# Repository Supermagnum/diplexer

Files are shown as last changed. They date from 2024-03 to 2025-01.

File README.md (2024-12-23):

# diplexer
HF+6M lowpass and 4M highpass

The lowpass filter has: 71.5mhz -42dB. 
Highpass filter 52.5mhz -45dB. 50.5mhz -50db

Highpass Ltspice analysis setup:
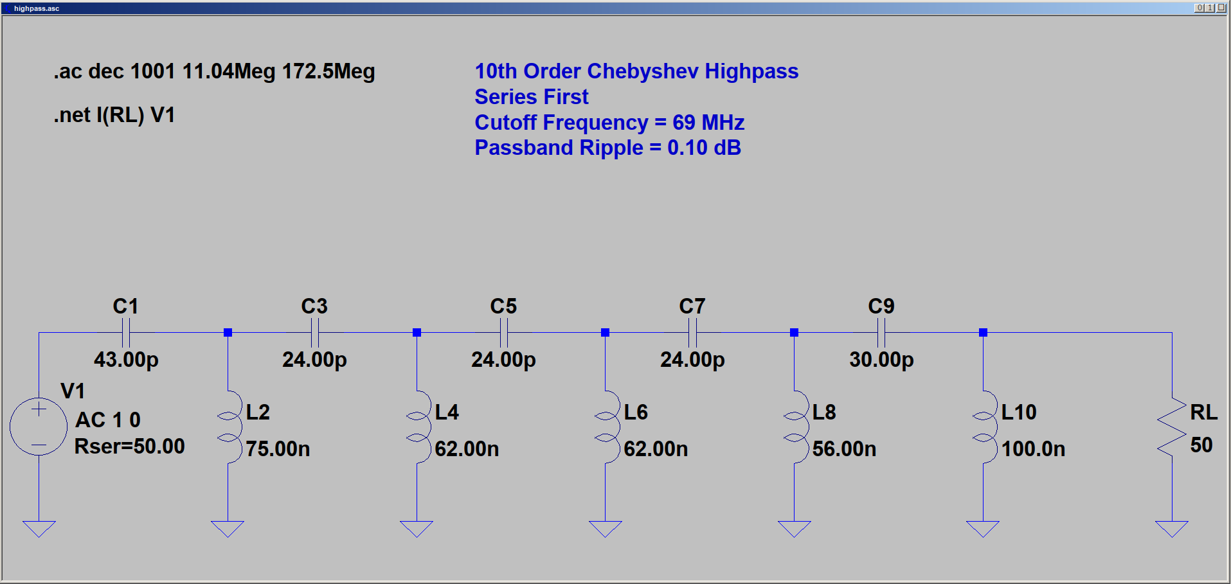
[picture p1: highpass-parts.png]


Highpass frequency analysis ( insertion loss, insertion phase, and return loss):
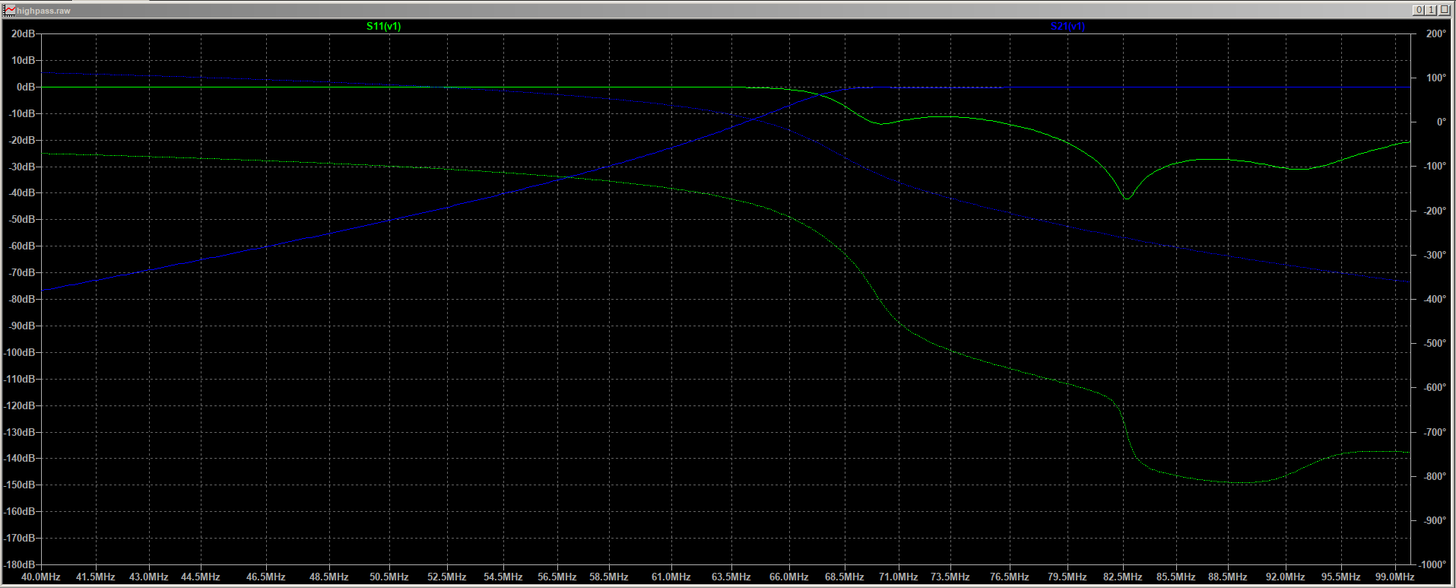
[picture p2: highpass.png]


Highpass Z-in and Z out analysis:
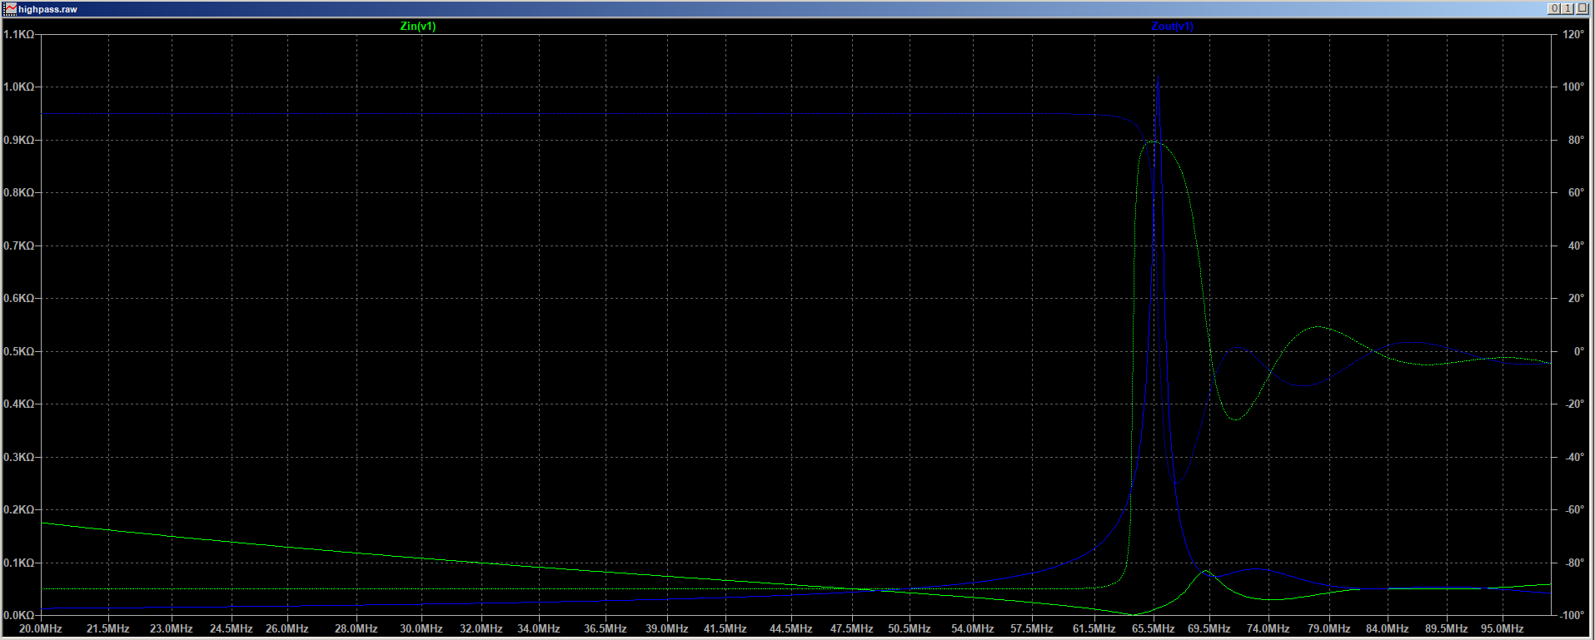
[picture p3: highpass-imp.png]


Lowpass LTspice analysis setup:
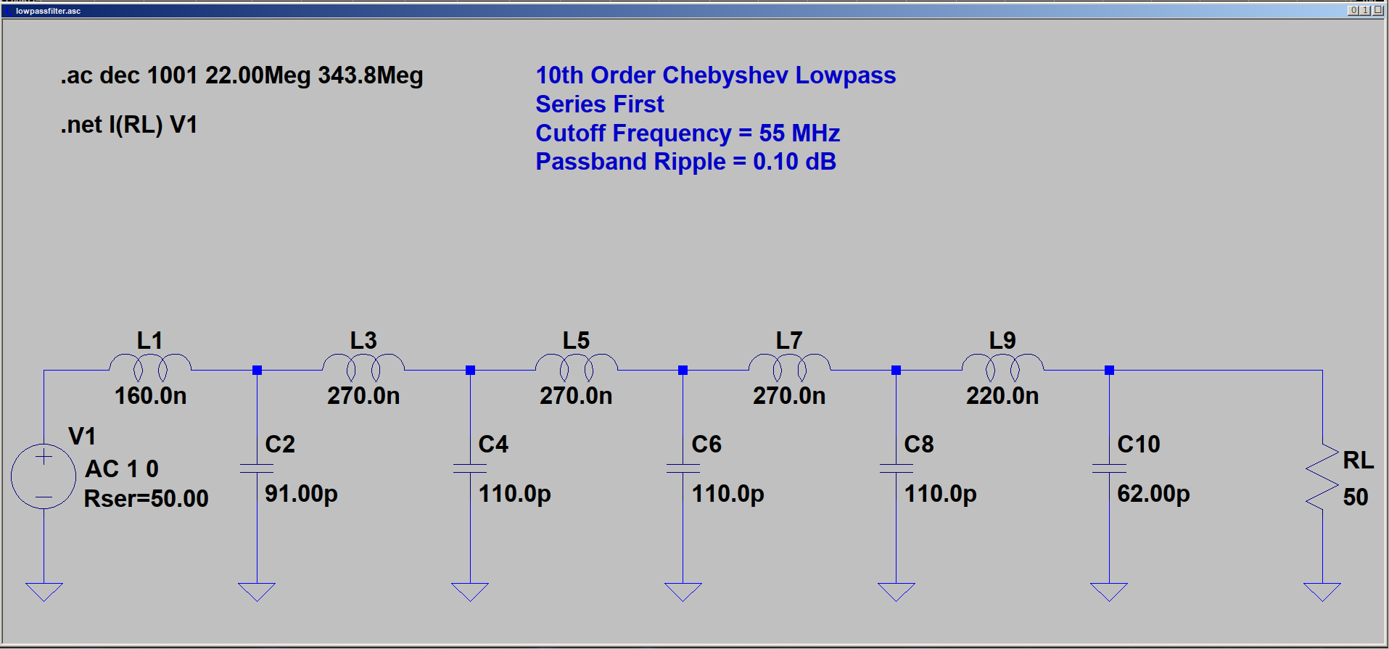
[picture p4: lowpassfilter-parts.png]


Lowpass filter frequency analysis ( insertion loss, insertion phase, and return loss):
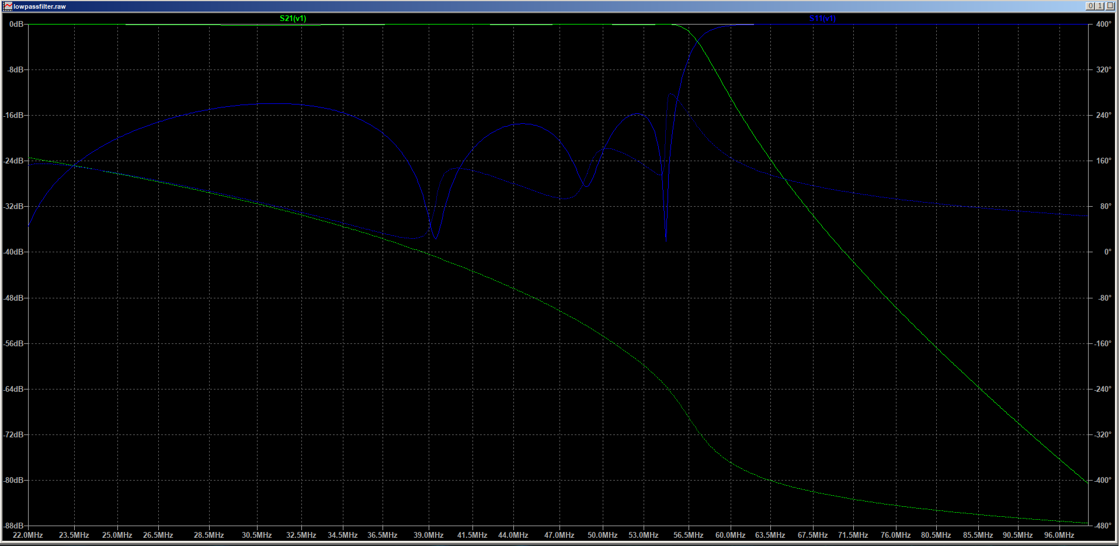
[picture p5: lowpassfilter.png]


Lowpass filter Z-in and Z out:
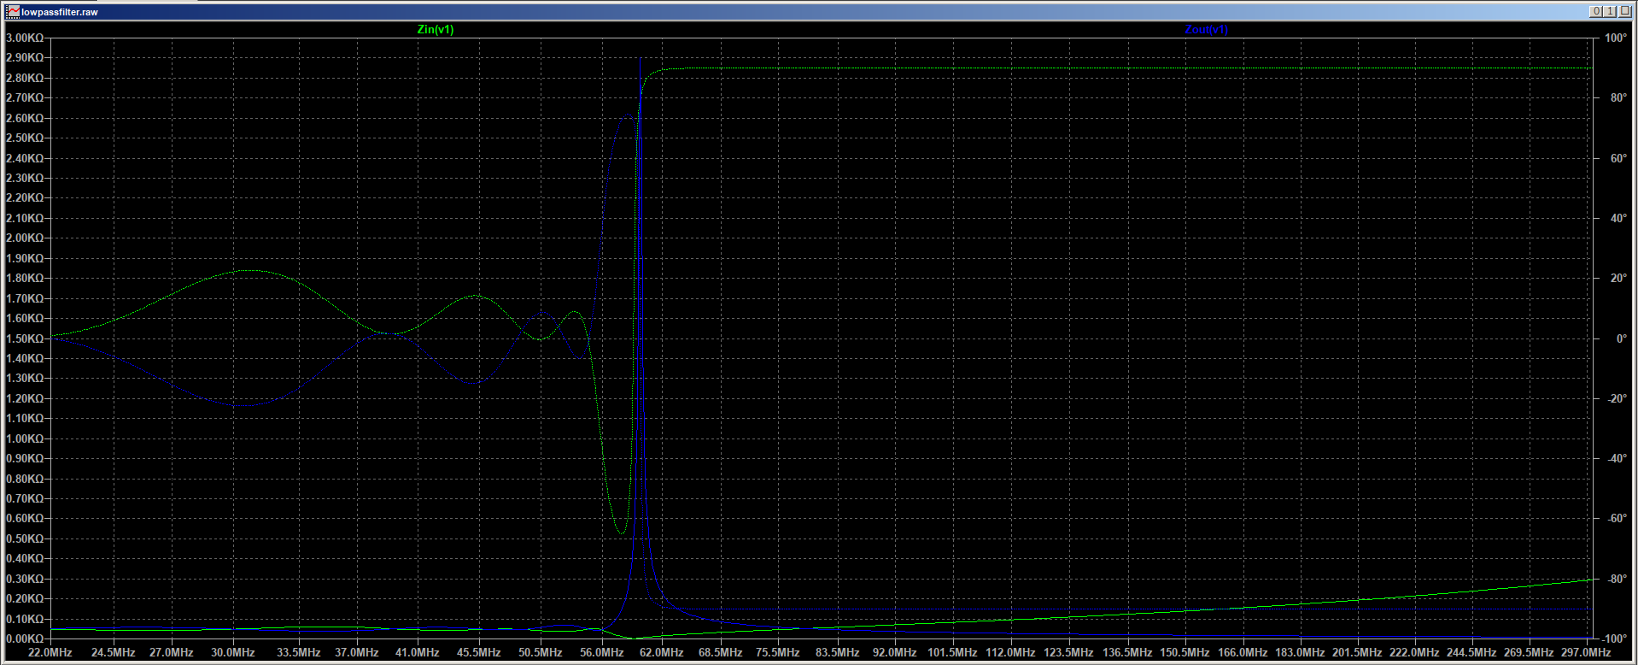
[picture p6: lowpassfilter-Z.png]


PCB board screenshot:
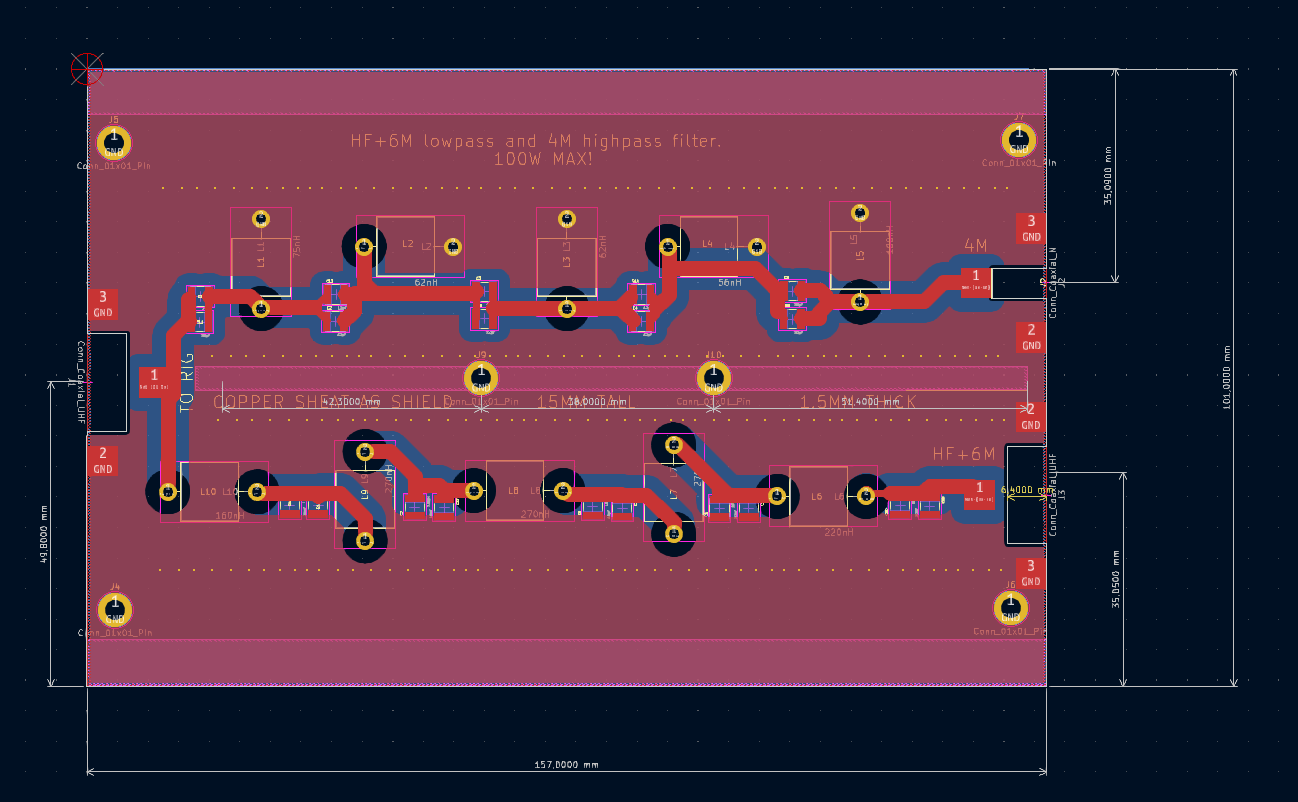
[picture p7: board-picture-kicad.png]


I had to draw the 1111 SMD footprint because it wasn't included in the Kicad database.
I hope that I haven't messed up.
Shematic for the diplexer:
https://raw.githubusercontent.com/Supermagnum/diplexer/refs/heads/main/diplexer.pdf

Inductors:
You have to make these yourself!
https://github.com/Supermagnum/diplexer/blob/main/Inductors.pdf

Suitable box:
https://www.hammfg.com/part/1457N1601E

All bolt holes is M3.

Animation of assembled PCB:
https://youtu.be/Ffxkk6wFYqY

PCB boards and assembly:
<a href="https://www.pcbway.com/project/shareproject/HF_6M_lowpass_and_4M_highpass_diplexer_af47343b.html">PCB from PCBWay</a>

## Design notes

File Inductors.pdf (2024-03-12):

❌

35 - 13.03.2024 00:37

## Coil64 v2.1.28 - One layer coil with round wire

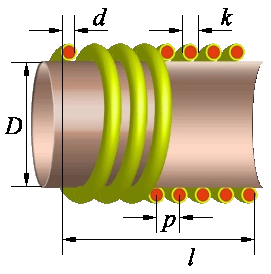
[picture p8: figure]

Input:
Inductance L: 220 nH
Frequency f: 50 MHz
Former diameter D: 9,5 mm
Wire diameter d: 1,5 mm
Wire diameter with insulation k: 1,635 mm Winding pitch p: 2 mm

Result:
Number of turns of the coil N = 5,561 Length of wire without leads lw = 19,484 cm Length of winding l = 12,757 mm
Weight of wire m = 3,085 g
Resistance of the coil Rdc = 0,002 Ohm Reactance of the coil X = 69,115 Ohm
Self capacitance Cs = 0,348 pF
Coil self-resonance frequency Fsr = 627,577 MHz Coil constructive Q-factor Q = 541
Loss resistance ESR = 0,127 Ohm

Additional results for parallel LC circuit at the working frequency: => Circuit capacitance: Ck = 45,707 pF
=> Characteristic impedance: ρ = 69 Ohm
=> Equivalent resistance: Re = 24,264 kOhm
=> Bandwidth: 3dBΔf = 142,421kHz

Input data for LTSpice:
Inductance: 0.220μ
Series resistance: 1.901m
Parallel resistance: 37.097k Parallel capacitance: 0.348p

❌

34 - 13.03.2024 00:36

## Coil64 v2.1.28 - One layer coil with round wire

Input:
Inductance L: 270 nH
Frequency f: 50 MHz
Former diameter D: 9,5 mm
Wire diameter d: 1,5 mm
Wire diameter with insulation k: 1,635 mm Winding pitch p: 2 mm

Result:
Number of turns of the coil N = 6,501 Length of wire without leads lw = 22,779 cm Length of winding l = 14,637 mm
Weight of wire m = 3,607 g
Resistance of the coil Rdc = 0,002 Ohm Reactance of the coil X = 84,823 Ohm
Self capacitance Cs = 0,36 pF
Coil self-resonance frequency Fsr = 566,705 MHz Coil constructive Q-factor Q = 541
Loss resistance ESR = 0,155 Ohm

Additional results for parallel LC circuit at the working frequency: => Circuit capacitance: Ck = 37,166 pF
=> Characteristic impedance: ρ = 85 Ohm
=> Equivalent resistance: Re = 29,779 kOhm
=> Bandwidth: 3dBΔf = 142,421kHz

Input data for LTSpice:
Inductance: 0.270μ
Series resistance: 2.222m
Parallel resistance: 45.416k Parallel capacitance: 0.360p

❌

33 - 13.03.2024 00:36

## Coil64 v2.1.28 - One layer coil with round wire

Input:
Inductance L: 160 nH
Frequency f: 50 MHz
Former diameter D: 9,5 mm
Wire diameter d: 1,5 mm
Wire diameter with insulation k: 1,635 mm Winding pitch p: 2 mm

Result:
Number of turns of the coil N = 4,387 Length of wire without leads lw = 15,371 cm Length of winding l = 10,409 mm
Weight of wire m = 2,434 g
Resistance of the coil Rdc = 0,001 Ohm Reactance of the coil X = 50,265 Ohm
Self capacitance Cs = 0,338 pF
Coil self-resonance frequency Fsr = 737,034 MHz Coil constructive Q-factor Q = 542
Loss resistance ESR = 0,092 Ohm

Additional results for parallel LC circuit at the working frequency: => Circuit capacitance: Ck = 62,988 pF
=> Characteristic impedance: ρ = 50 Ohm
=> Equivalent resistance: Re = 17,668 kOhm
=> Bandwidth: 3dBΔf = 142,251kHz

Input data for LTSpice:
Inductance: 0.160μ
Series resistance: 1.500m
Parallel resistance: 27.108k Parallel capacitance: 0.338p

❌

32 - 13.03.2024 00:35

## Coil64 v2.1.28 - One layer coil with round wire

Input:
Inductance L: 100 nH
Frequency f: 50 MHz
Former diameter D: 9,5 mm
Wire diameter d: 1,5 mm
Wire diameter with insulation k: 1,635 mm Winding pitch p: 2 mm

Result:
Number of turns of the coil N = 3,166 Length of wire without leads lw = 11,095 cm Length of winding l = 7,968 mm
Weight of wire m = 1,757 g
Resistance of the coil Rdc = 0,001 Ohm Reactance of the coil X = 31,416 Ohm
Self capacitance Cs = 0,337 pF
Coil self-resonance frequency Fsr = 929,365 MHz Coil constructive Q-factor Q = 534
Loss resistance ESR = 0,059 Ohm

Additional results for parallel LC circuit at the working frequency: => Circuit capacitance: Ck = 100,984 pF
=> Characteristic impedance: ρ = 31 Ohm
=> Equivalent resistance: Re = 10,936 kOhm
=> Bandwidth: 3dBΔf = 143,633kHz

Input data for LTSpice:
Inductance: 0.100μ
Series resistance: 1.082m
Parallel resistance: 16.730k Parallel capacitance: 0.337p

❌

31 - 13.03.2024 00:32

## Coil64 v2.1.28 - One layer coil with round wire

Input:
Inductance L: 75 nH
Frequency f: 50 MHz
Former diameter D: 9,5 mm
Wire diameter d: 1,5 mm
Wire diameter with insulation k: 1,635 mm Winding pitch p: 2 mm

Result:
Number of turns of the coil N = 2,581 Length of wire without leads lw = 9,042 cm Length of winding l = 6,796 mm
Weight of wire m = 1,432 g
Resistance of the coil Rdc = 0,001 Ohm Reactance of the coil X = 23,562 Ohm
Self capacitance Cs = 0,345 pF
Coil self-resonance frequency Fsr = 1 079,823 MHz Coil constructive Q-factor Q = 535
Loss resistance ESR = 0,044 Ohm

Additional results for parallel LC circuit at the working frequency: => Circuit capacitance: Ck = 134,75 pF
=> Characteristic impedance: ρ = 24 Ohm
=> Equivalent resistance: Re = 8,212 kOhm
=> Bandwidth: 3dBΔf = 143,458kHz

Input data for LTSpice:
Inductance: 0.075μ
Series resistance: 0.882m
Parallel resistance: 12.565k Parallel capacitance: 0.345p

❌

30 - 13.03.2024 00:32

## Coil64 v2.1.28 - One layer coil with round wire

Input:
Inductance L: 56 nH
Frequency f: 50 MHz
Former diameter D: 9,5 mm
Wire diameter d: 1,5 mm
Wire diameter with insulation k: 1,635 mm Winding pitch p: 2 mm

Result:
Number of turns of the coil N = 2,144 Length of wire without leads lw = 7,512 cm Length of winding l = 5,923 mm
Weight of wire m = 1,189 g
Resistance of the coil Rdc = 0,001 Ohm Reactance of the coil X = 17,593 Ohm
Self capacitance Cs = 0,356 pF
Coil self-resonance frequency Fsr = 1 239,228 MHz Coil constructive Q-factor Q = 514
Loss resistance ESR = 0,034 Ohm

Additional results for parallel LC circuit at the working frequency: => Circuit capacitance: Ck = 180,575 pF
=> Characteristic impedance: ρ = 18 Ohm
=> Equivalent resistance: Re = 5,973 kOhm
=> Bandwidth: 3dBΔf = 147,276kHz

Input data for LTSpice:
Inductance: 0.056μ
Series resistance: 0.733m
Parallel resistance: 9.017k Parallel capacitance: 0.356p

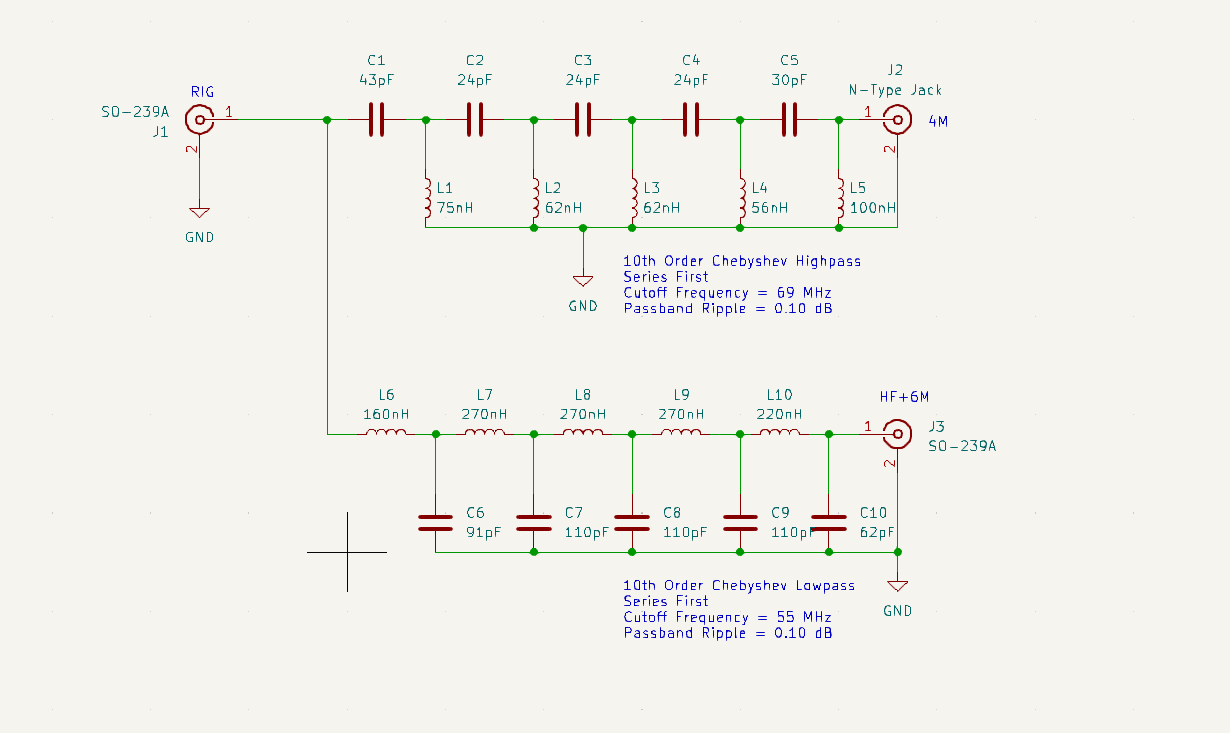
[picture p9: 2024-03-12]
schematic.png

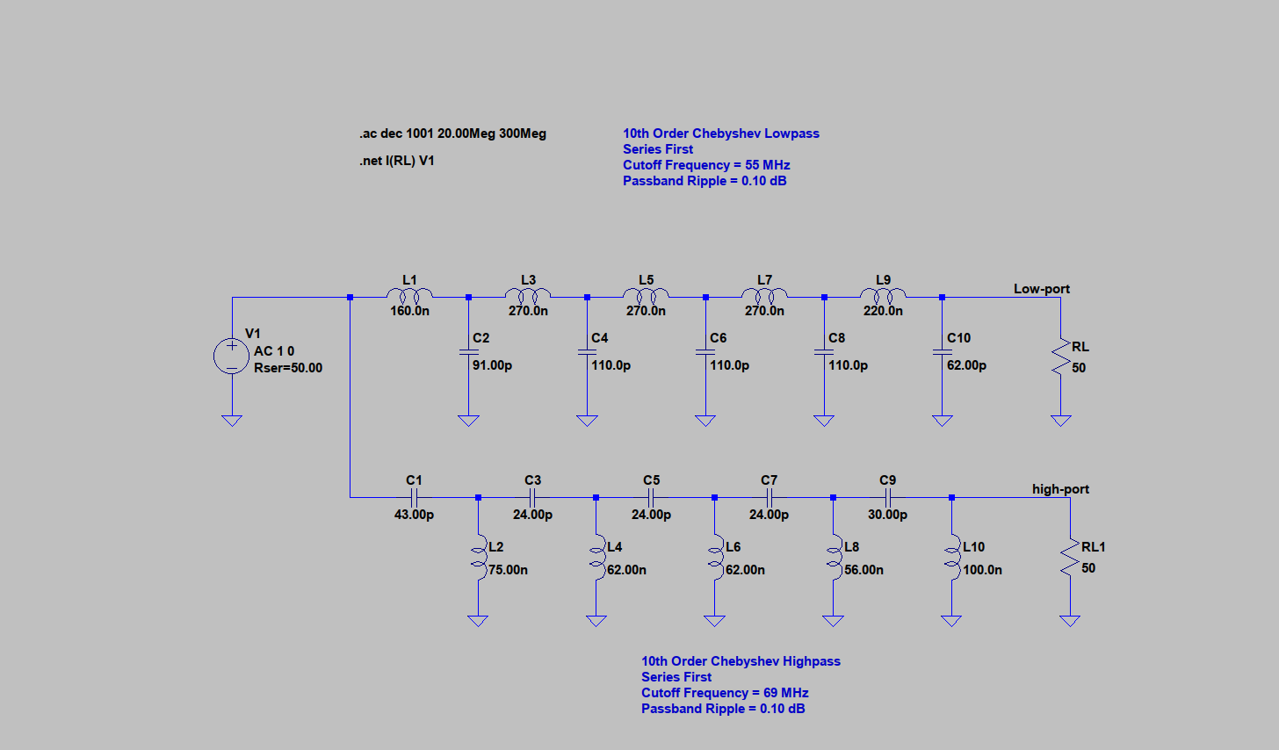
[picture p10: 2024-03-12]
diplexer.png

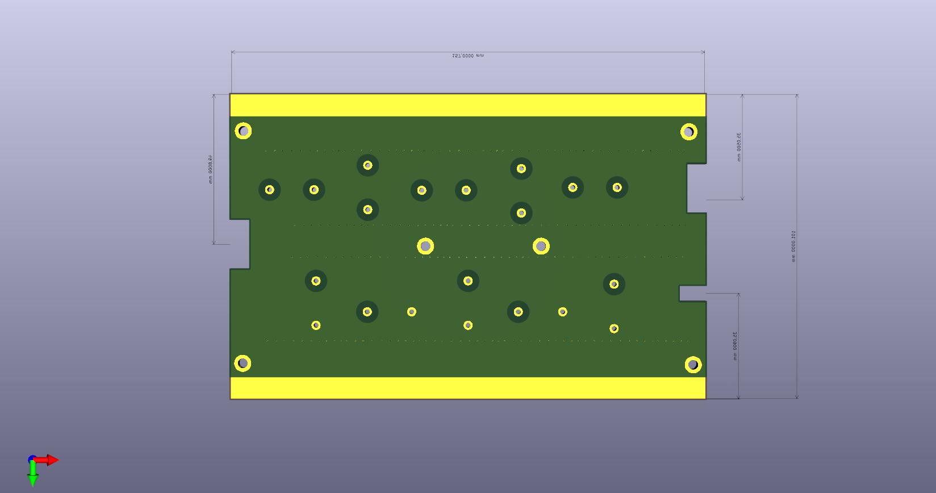
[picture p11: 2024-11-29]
diplexer2.jpg

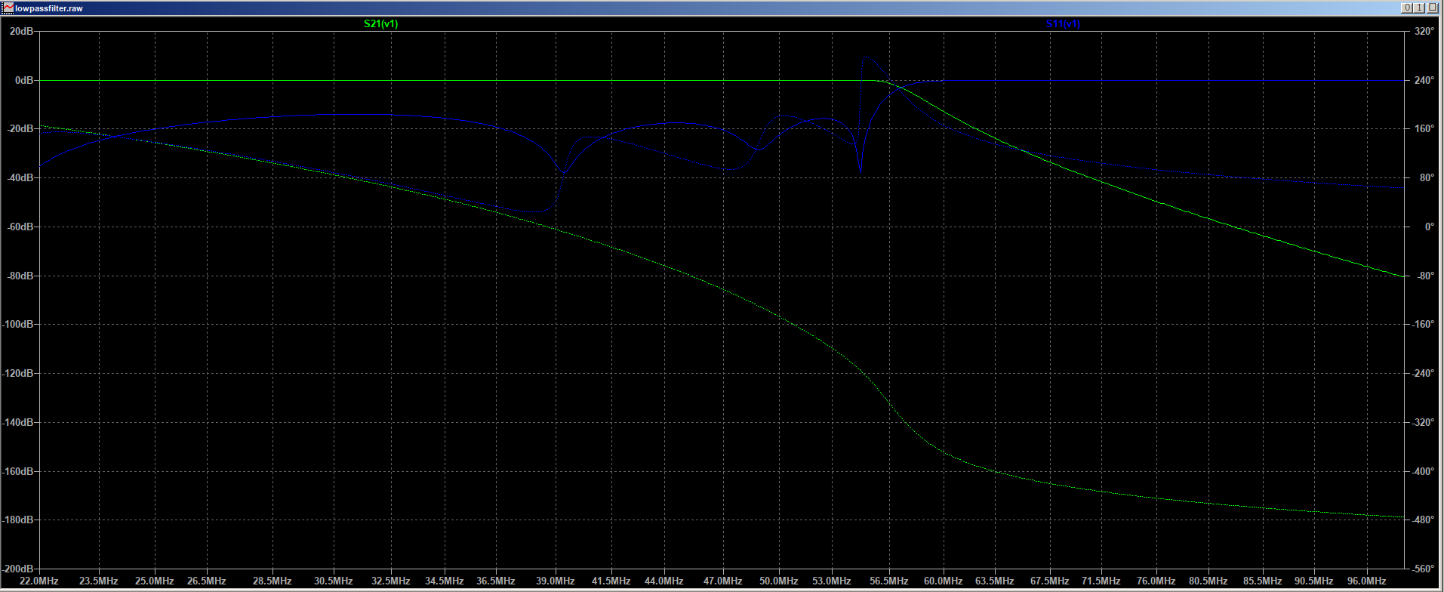
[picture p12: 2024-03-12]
lowpass.png

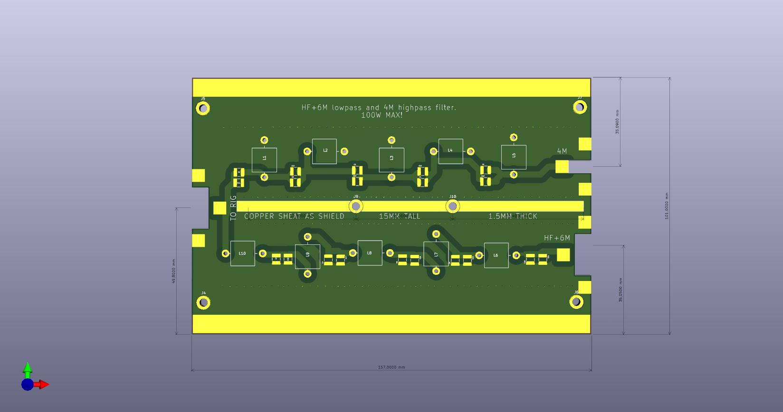
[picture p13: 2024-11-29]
diplexer.jpg

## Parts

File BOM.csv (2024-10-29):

Reference | Value | Datasheet | Qty | MPN
C6 | 75pF | ~ | 1 | VJ1111D750JXGAJ
C11 | 30pF | ~ | 1 | VJ1111D300GXGQT
C5 | 20pF | ~ | 1 | VJ1111D200JXRAJ
C1 | 13pF | ~ | 1 | VJ1111D130JXGAJ
C2,C3,C4,C12,C13,C14 | 12pF | ~ | 6 | VJ1111D120GXGQJ
C7,C8,C9 | 100pF | ~ | 3 | VJ1111D101GXGQT
C15,C17,C18,C19 | 10pF | ~ | 4 | VJ1111D100JXRAJ
C10 | 39pF |  | 1 | VJ1111D390JXRAJ
C16 | 16pF | ~ | 1 | VJ1111D160GXGQT
C20 | 22pF |  | 1 | VJ1111D220JXRAJ

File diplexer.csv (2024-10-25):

# | Reference | Qty | Value | Footprint | DNP
1 | C1 | 1 | 13pF | sparkfun-electromech:1111
2 | C2, C3, C4, C12, C13, C14 | 6 | 12pF | sparkfun-electromech:1111
3 | C5 | 1 | 20pF | sparkfun-electromech:1111
4 | C6 | 1 | 75pF | sparkfun-electromech:1111
5 | C7, C8, C9 | 3 | 100pF | sparkfun-electromech:1111
6 | C10 | 1 | 39pF | sparkfun-electromech:1111
7 | C11 | 1 | 30pF | sparkfun-electromech:1111
8 | C15, C17, C18, C19 | 4 | 10pF | sparkfun-electromech:1111
9 | C16 | 1 | 16pF | sparkfun-electromech:1111
10 | C20 | 1 | 22pF | sparkfun-electromech:1111
11 | J1, J3 | 2 | Conn_Coaxial | sparkfun-electromech:UHF slanted
12 | J2 | 1 | Conn_Coaxial | sparkfun-electromech:N-conn slanted
13 | J4, J5, J6, J7, J8, J9, J10, J11 | 8 | Conn_01x01_Pin | MountingHole:MountingHole_3.2mm_M3_DIN965_Pad
14 | L1 | 1 | 75nH | sparkfun-electromech:L_Axial_L14.6-hand
15 | L2, L3 | 2 | 62nH | sparkfun-electromech:L_Axial_L14.6-hand
16 | L4 | 1 | 56nH | sparkfun-electromech:L_Axial_L14.6-hand
17 | L5 | 1 | 100nH | sparkfun-electromech:L_Axial_L14.6-hand
18 | L6 | 1 | 220nH | sparkfun-electromech:L_Axial_L14.6-hand
19 | L7, L8, L9 | 3 | 270nH | sparkfun-electromech:L_Axial_L14.6-hand
20 | L10 | 1 | 160nH | sparkfun-electromech:L_Axial_L14.6-hand

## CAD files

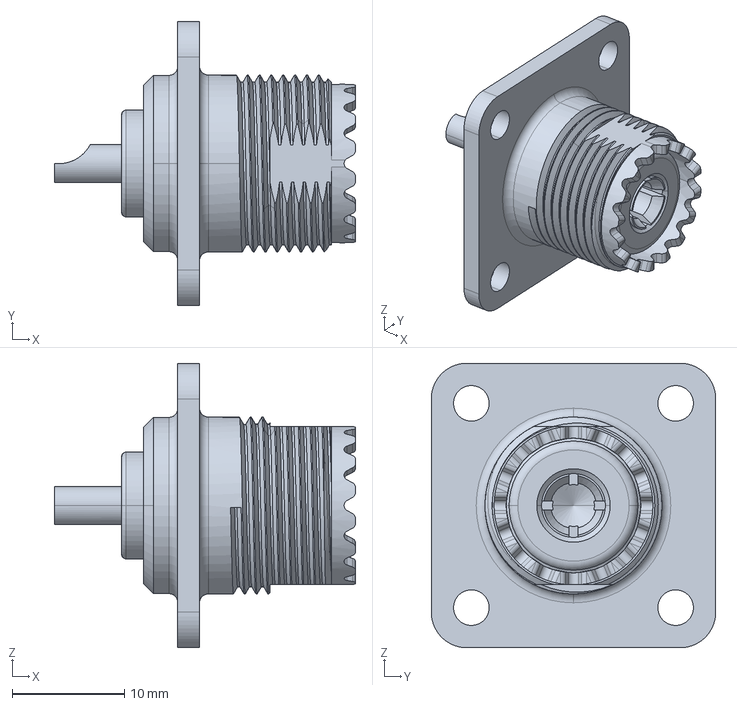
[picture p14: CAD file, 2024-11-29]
3D/083-1R/3D/083-1R.stp
26.9 x 25.4 x 25.4 mm

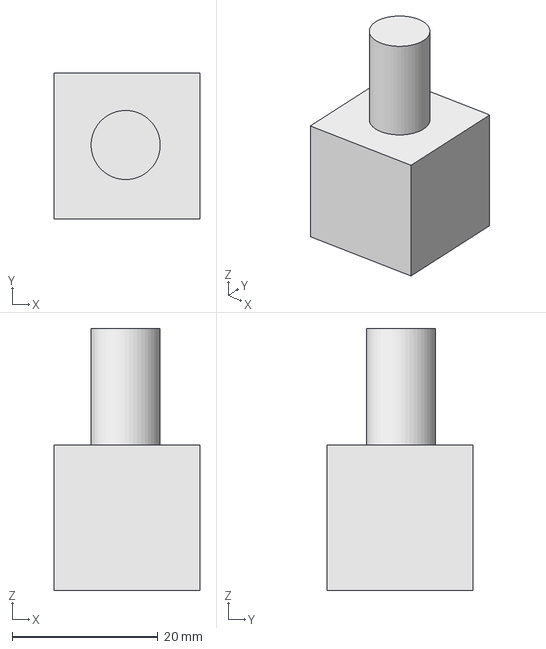
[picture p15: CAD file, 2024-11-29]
3D/Coil form.FCStd
20.0 x 20.0 x 36.0 mm

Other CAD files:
3D/Coil form-Body.stl
Coil form.FCStd

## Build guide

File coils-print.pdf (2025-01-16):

❌ – 7 - 04.01.2025 10:51
Coil64 v2.2.33 - One layer close-winding coil

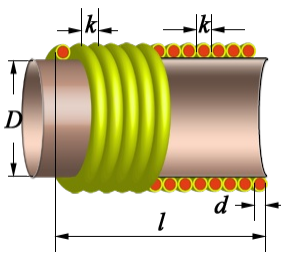
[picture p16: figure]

Input:
Inductance L: 270 nH
Frequency f: 50 MHz
Former diameter D: 9,5 mm
Wire diameter d: 1,5 mm
Wire diameter with insulation k: 1,635 mm Wire material Mt: Copper

Result:
Number of turns of the coil N = 5,948 Length of wire without leads lw = 20,831 cm Length of winding l = 11,361 mm
Weight of wire m = 3,298 g
Resistance of the coil Rdc = 0,002 Ohm Reactance of the coil X = 84,823 Ohm

Self capacitance Cs = 0,341 pF
Coil self-resonance frequency Fsr = 561,687 MHz Coil constructive Q-factor Q = 431
Loss resistance ESR = 0,195 Ohm

Additional results for parallel LC circuit at the working frequency: => Circuit capacitance: Ck = 37,185 pF
=> Characteristic impedance: ρ = 85 Ohm
=> Equivalent resistance: Re = 25,548 kOhm
=> Bandwidth: 3dBΔf = 166,009 kHz

Input data for LTSpice:
Inductance: 0.270μ
Series resistance: 2.032m
Parallel resistance: 36.197k Parallel capacitance: 0.341p

❌ – 6 - 04.01.2025 10:51
Coil64 v2.2.33 - One layer close-winding coil

Input:
Inductance L: 160 nH
Frequency f: 50 MHz
Former diameter D: 9,5 mm
Wire diameter d: 1,5 mm
Wire diameter with insulation k: 1,635 mm Wire material Mt: Copper

Result:
Number of turns of the coil N = 4,096 Length of wire without leads lw = 14,343 cm Length of winding l = 8,331 mm
Weight of wire m = 2,271 g
Resistance of the coil Rdc = 0,001 Ohm Reactance of the coil X = 50,265 Ohm

Self capacitance Cs = 0,336 pF
Coil self-resonance frequency Fsr = 730,051 MHz Coil constructive Q-factor Q = 458
Loss resistance ESR = 0,109 Ohm

Additional results for parallel LC circuit at the working frequency: => Circuit capacitance: Ck = 62,989 pF
=> Characteristic impedance: ρ = 50 Ohm
=> Equivalent resistance: Re = 15,79 kOhm
=> Bandwidth: 3dBΔf = 159,17 kHz

Input data for LTSpice:
Inductance: 0.160μ
Series resistance: 1.399m
Parallel resistance: 22.923k

Parallel capacitance: 0.336p

❌ – 5 - 04.01.2025 10:51
Coil64 v2.2.33 - One layer close-winding coil

Input:
Inductance L: 100 nH
Frequency f: 50 MHz
Former diameter D: 9,5 mm
Wire diameter d: 1,5 mm
Wire diameter with insulation k: 1,635 mm Wire material Mt: Copper

Result:
Number of turns of the coil N = 3,003 Length of wire without leads lw = 10,516 cm Length of winding l = 6,545 mm
Weight of wire m = 1,665 g
Resistance of the coil Rdc = 0,001 Ohm Reactance of the coil X = 31,416 Ohm

Self capacitance Cs = 0,347 pF
Coil self-resonance frequency Fsr = 916,509 MHz Coil constructive Q-factor Q = 474
Loss resistance ESR = 0,066 Ohm

Additional results for parallel LC circuit at the working frequency: => Circuit capacitance: Ck = 100,974 pF
=> Characteristic impedance: ρ = 31 Ohm
=> Equivalent resistance: Re = 10,103 kOhm
=> Bandwidth: 3dBΔf = 155,485 kHz

Input data for LTSpice:
Inductance: 0.100μ

Series resistance: 1.026m
Parallel resistance: 14.826k Parallel capacitance: 0.347p

❌ – 4 - 04.01.2025 10:51
Coil64 v2.2.33 - One layer close-winding coil

Input:
Inductance L: 56 nH
Frequency f: 50 MHz
Former diameter D: 9,5 mm
Wire diameter d: 1,5 mm
Wire diameter with insulation k: 1,635 mm Wire material Mt: Copper

Result:
Number of turns of the coil N = 2,071 Length of wire without leads lw = 7,254 cm Length of winding l = 5,022 mm
Weight of wire m = 1,149 g
Resistance of the coil Rdc = 0,001 Ohm
Reactance of the coil X = 17,593 Ohm

Self capacitance Cs = 0,378 pF
Coil self-resonance frequency Fsr = 1 209,051 MHz Coil constructive Q-factor Q = 484
Loss resistance ESR = 0,036 Ohm

Additional results for parallel LC circuit at the working frequency: => Circuit capacitance: Ck = 180,553 pF
=> Characteristic impedance: ρ = 18 Ohm
=> Equivalent resistance: Re = 5,738 kOhm
=> Bandwidth: 3dBΔf = 153,306 kHz

Input data for LTSpice:
Inductance: 0.056μ
Series resistance: 0.708m
Parallel resistance: 8.491k Parallel capacitance: 0.378p

❌ – 3 - 04.01.2025 10:50
Coil64 v2.2.33 - One layer close-winding coil

Input:
Inductance L: 62 nH
Frequency f: 50 MHz
Former diameter D: 9,5 mm
Wire diameter d: 1,5 mm
Wire diameter with insulation k: 1,635 mm Wire material Mt: Copper

Result:
Number of turns of the coil N = 2,192 Length of wire without leads lw = 7,677 cm Length of winding l = 5,219 mm
Weight of wire m = 1,216 g
Resistance of the coil Rdc = 0,001 Ohm
Reactance of the coil X = 19,478 Ohm

Self capacitance Cs = 0,372 pF
Coil self-resonance frequency Fsr = 1 158,755 MHz Coil constructive Q-factor Q = 492
Loss resistance ESR = 0,04 Ohm

Additional results for parallel LC circuit at the working frequency: => Circuit capacitance: Ck = 163,049 pF
=> Characteristic impedance: ρ = 19 Ohm
=> Equivalent resistance: Re = 6,423 kOhm
=> Bandwidth: 3dBΔf = 151,626 kHz

Input data for LTSpice:
Inductance: 0.062μ
Series resistance: 0.749m
Parallel resistance: 9.566k Parallel capacitance: 0.372p

❌ – 2 - 04.01.2025 10:50
Coil64 v2.2.33 - One layer close-winding coil

Input:
Inductance L: 75 nH
Frequency f: 50 MHz
Former diameter D: 9,5 mm
Wire diameter d: 1,5 mm
Wire diameter with insulation k: 1,635 mm Wire material Mt: Copper

Result:
Number of turns of the coil N = 2,457 Length of wire without leads lw = 8,605 cm Length of winding l = 5,652 mm
Weight of wire m = 1,362 g
Resistance of the coil Rdc = 0,001 Ohm
Reactance of the coil X = 23,562 Ohm

Self capacitance Cs = 0,361 pF
Coil self-resonance frequency Fsr = 1 064,069 MHz Coil constructive Q-factor Q = 497
Loss resistance ESR = 0,047 Ohm

Additional results for parallel LC circuit at the working frequency: => Circuit capacitance: Ck = 134,734 pF
=> Characteristic impedance: ρ = 24 Ohm
=> Equivalent resistance: Re = 7,823 kOhm

=> Bandwidth: 3dBΔf = 150,604 kHz

Input data for LTSpice:
Inductance: 0.075μ
Series resistance: 0.839m
Parallel resistance: 11.675k Parallel capacitance: 0.361p

❌ – 1 - 28.12.2024 11:15
Coil64 v2.2.33 - One layer close-winding coil

Input:
Inductance L: 220 nH
Frequency f: 50 MHz
Former diameter D: 9,5 mm
Wire diameter d: 1,5 mm
Wire diameter with insulation k: 1,635 mm Wire material Mt: Copper

Result:
Number of turns of the coil N = 5,124 Length of wire without leads lw = 17,943 cm Length of winding l = 10,012 mm
Weight of wire m = 2,841 g
Resistance of the coil Rdc = 0,002 Ohm Reactance of the coil X = 69,115 Ohm

Self capacitance Cs = 0,337 pF
Coil self-resonance frequency Fsr = 622,581 MHz Coil constructive Q-factor Q = 442
Loss resistance ESR = 0,155 Ohm

Additional results for parallel LC circuit at the working frequency: => Circuit capacitance: Ck = 45,718 pF

=> Characteristic impedance: ρ = 69 Ohm => Equivalent resistance: Re = 21,185 kOhm => Bandwidth: 3dBΔf = 163,122 kHz

Input data for LTSpice:
Inductance: 0.220μ
Series resistance: 1.751m
Parallel resistance: 30.296k Parallel capacitance: 0.337p

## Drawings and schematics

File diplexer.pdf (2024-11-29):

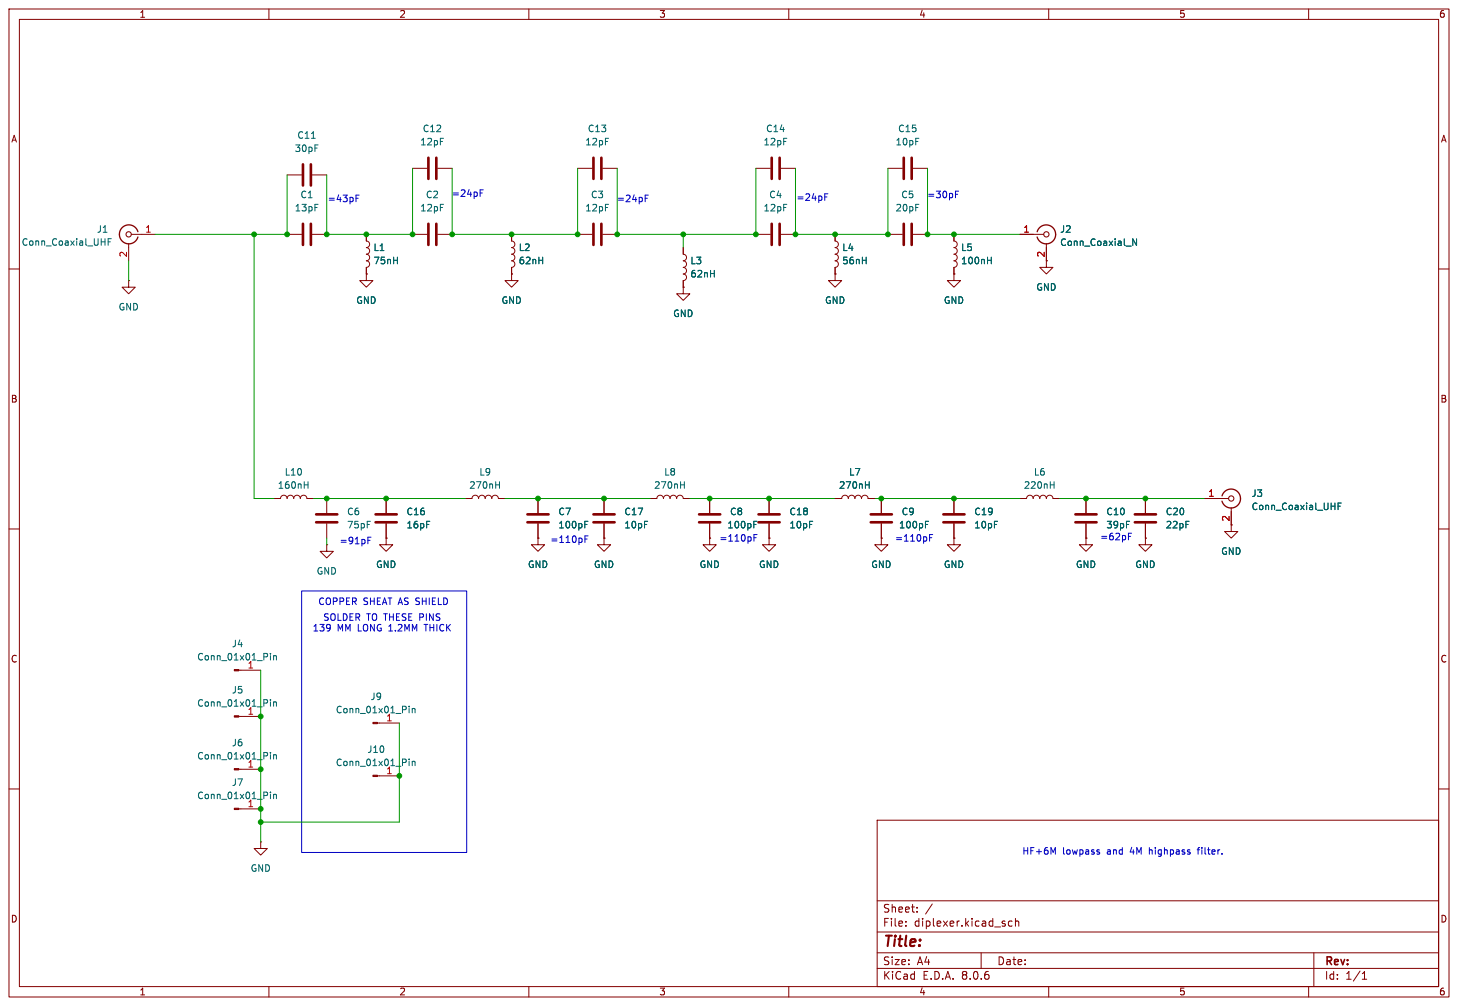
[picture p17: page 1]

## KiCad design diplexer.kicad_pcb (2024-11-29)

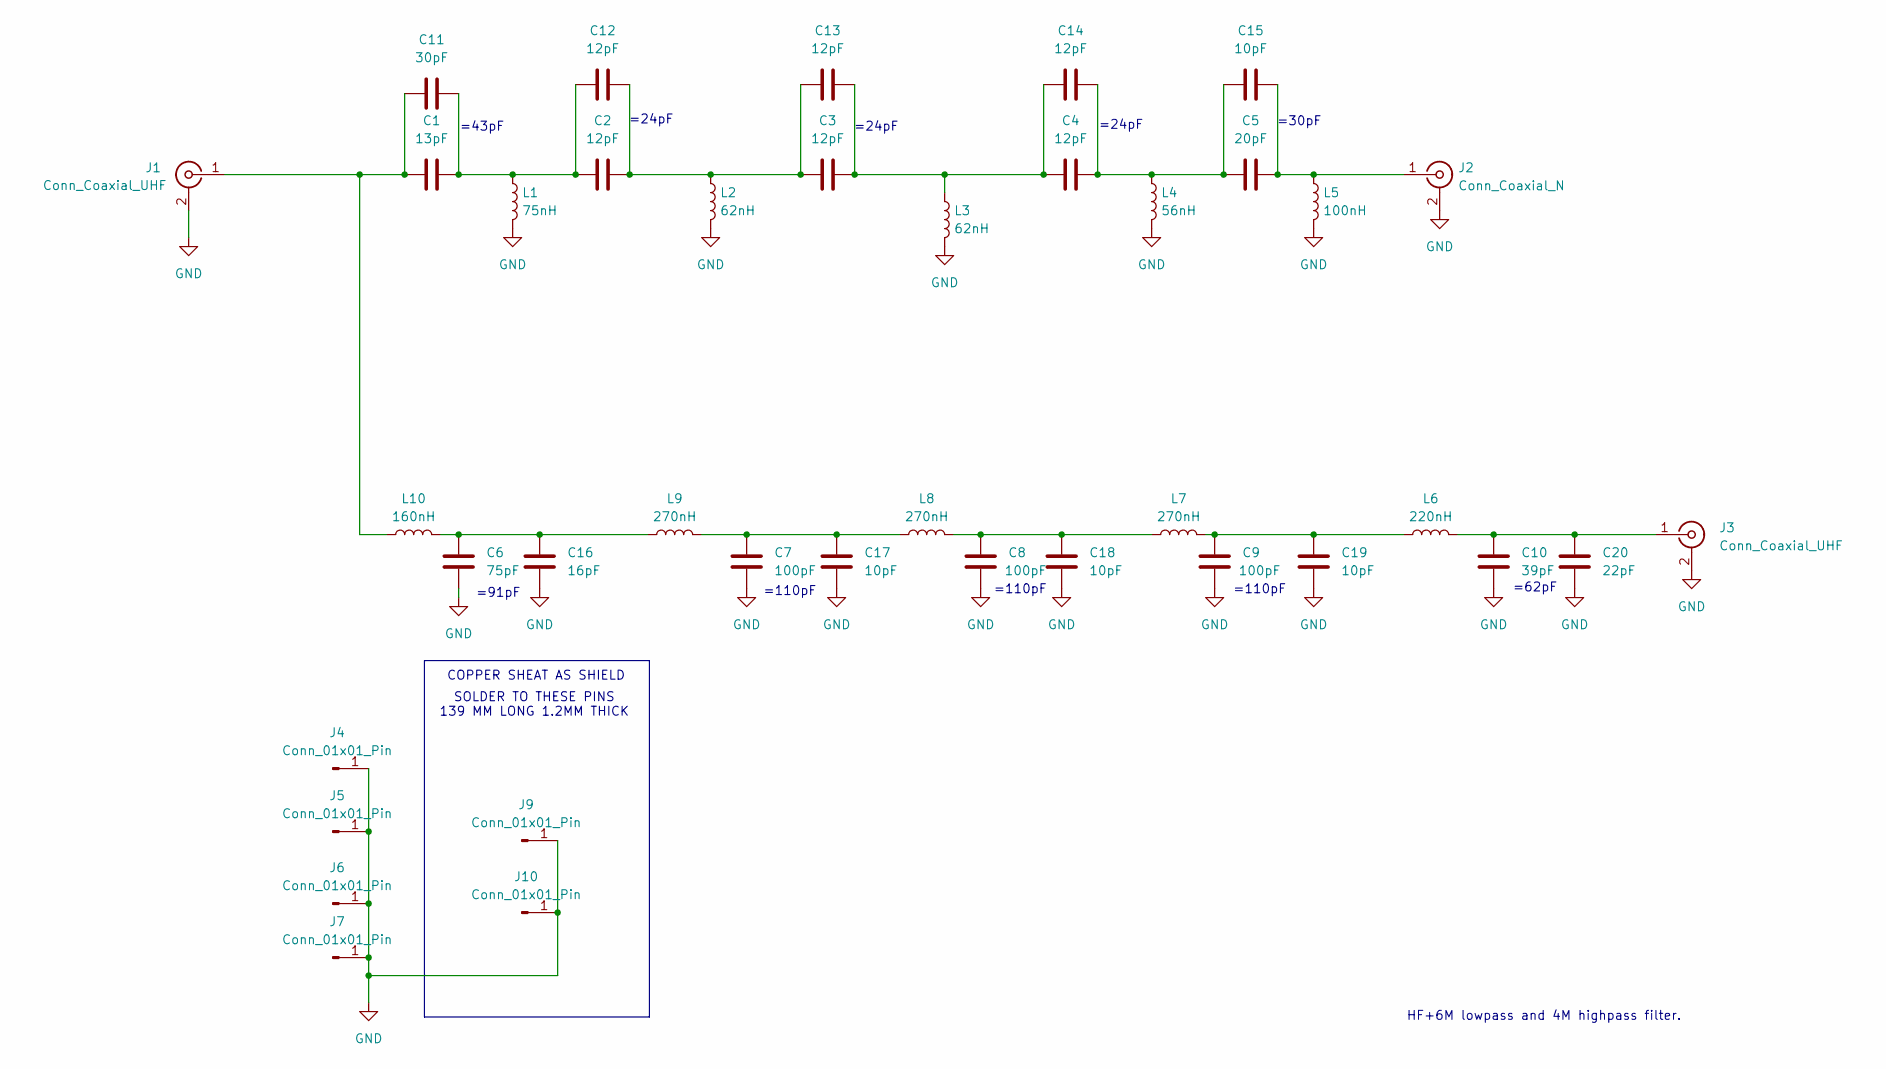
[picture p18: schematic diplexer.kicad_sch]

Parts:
C1: 13pF; CAPC2927X178N; MPN VJ1111D130JXGAJ
C2, C3, C4, C12, C13, C14: 12pF; CAPC2927X178N; MPN VJ1111D120GXGQJ
C5: 20pF; CAPC2927X178N; MPN VJ1111D200JXRAJ
C6: 75pF; CAPC2927X178N; MPN VJ1111D750JXGAJ
C7, C8, C9: 100pF; CAPC2927X178N; MPN VJ1111D101GXGQT
C10: 39pF; CAPC2927X178N; MPN VJ1111D390JXRAJ
C11: 30pF; CAPC2927X178N; MPN VJ1111D300GXGQT
C15, C17, C18, C19: 10pF; CAPC2927X178N; MPN VJ1111D100JXRAJ
C16: 16pF; CAPC2927X178N; MPN VJ1111D160GXGQT
C20: 22pF; CAPC2927X178N; MPN VJ1111D220JXRAJ
J1: Conn_Coaxial_UHF; UHF-slant-corr; MPN 083-1R (SO-239)
J2: Conn_Coaxial_N; Conn-N-slant-C; MPN 172117
J3: Conn_Coaxial_UHF; UHF-slant-corr; MPN 83-1R (SO-239)
J4, J5, J6, J7, J9, J10: Conn_01x01_Pin; MountingHole_3.2mm_M3_DIN965_Pad
L1: 75nH; L_Axial_L14.6-hand
L2, L3: 62nH; L_Axial_L14.6-hand
L4: 56nH; L_Axial_L14.6-hand
L5: 100nH; L_Axial_L14.6-hand
L6: 220nH; L_Axial_L14.6-hand
L7, L8, L9: 270nH; L_Axial_L14.6-hand
L10: 160nH; L_Axial_L14.6-hand

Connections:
GND: C6.1, C7.1, C8.1, C9.1, C10.1, C16.2, C17.2, C18.2, C19.2, C20.2, J1.2 (Ext), J1.3, J2.2 (Ext), J2.3, J3.2 (Ext), J3.3, J4.1, J5.1, J6.1, J7.1, J9.1, J10.1, L1.2, L2.2, L3.2, L4.2, L5.2
unnamed: C1.2, C2.1, C11.2, C12.1, L1.1
unnamed: C2.2, C3.1, C12.2, C13.1, L2.1
unnamed: C3.2, C4.1, C13.2, C14.1, L3.1
unnamed: C4.2, C5.1, C14.2, C15.1, L4.1
unnamed: C6.2, C16.1, L9.1, L10.2
unnamed: C7.2, C17.1, L8.1, L9.2
unnamed: C8.2, C18.1, L7.1, L8.2
unnamed: C9.2, C19.1, L6.1, L7.2
unnamed: C1.1, C11.1, J1.1 (In), L10.1
unnamed: C5.2, C15.2, J2.1 (In), L5.1
unnamed: C10.2, C20.1, J3.1 (In), L6.2

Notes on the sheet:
=24pF
=110pF
=43pF
=91pF
=62pF
COPPER SHEAT AS SHIELD
SOLDER TO THESE PINS 139 MM LONG 1.2MM THICK
HF+6M lowpass and 4M highpass filter.
=30pF

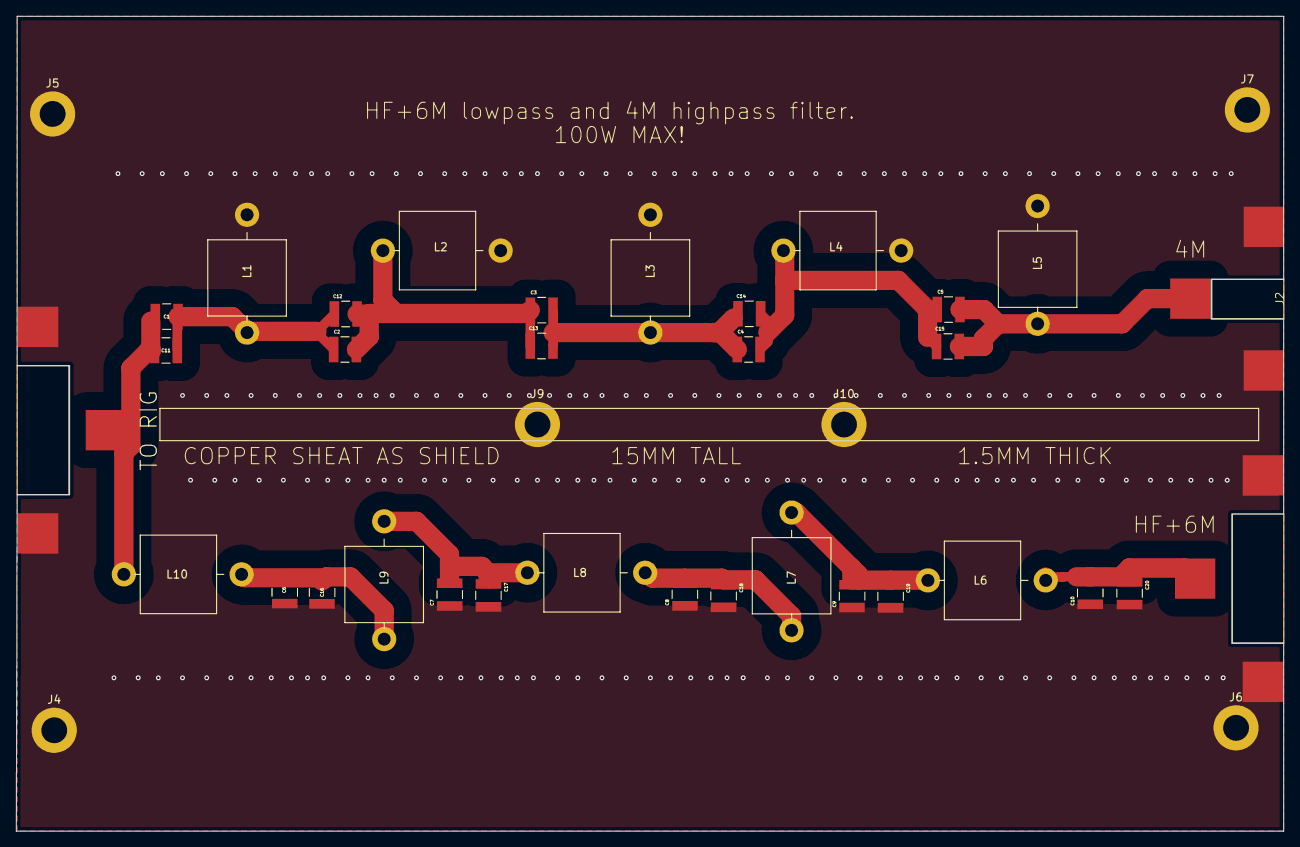
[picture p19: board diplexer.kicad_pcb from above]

Board: 2 copper layers, 157.1 x 101.0 mm, 39 parts (0 on the bottom side), 12 nets.

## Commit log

2024-10-11 Add files via upload
    Added gerber and kicad files.
    [diplexer-B_Cu.gbr, diplexer-B_Mask.gbr, diplexer-B_Paste.gbr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]
2024-10-12 Add files via upload
    Updated capacitors foot prints to 2525 (QEEV Series)
    [diplexer-B_Cu.gbr, diplexer-B_Mask.gbr, diplexer-B_Paste.gbr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]
2024-10-13 Delete Gerbers/Gerbers.zip
    outdated
2024-11-29 Add files via upload
    Added cutouts for connectors
    [083-1R.stp, Coil form-Body.stl, Coil form.FCStd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]
2024-11-29 Add files via upload
    fixed old pictures
    [diplexer-B_Cu.gbr, diplexer-B_Mask.gbr, diplexer-B_Paste.gbr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]
